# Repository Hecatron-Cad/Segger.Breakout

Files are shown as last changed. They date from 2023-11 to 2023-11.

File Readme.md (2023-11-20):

# Segger Breakout

This is a simple kicad design for a breakout board for the JLink Segger.

  * https://www.segger.com/products/debug-probes/j-link/models/j-link-edu/

It also has pads for connecting an ESP32 ProS3, or a Rpi Pico 2040
To clone use
```sh
git clone --recurse-submodules https://github.com/Hecatron-Cad/Segger.Breakout.git
```

## VCC Pins

I've added a jumper for the VCC input to VTref on the segger.
some pages suggest not to connect it when the device is powered over usb, but I think this is incorrect.
Still I added a jumper just in case anyway

  * https://www.visualmicro.com/page/ESP32-Debugging.aspx

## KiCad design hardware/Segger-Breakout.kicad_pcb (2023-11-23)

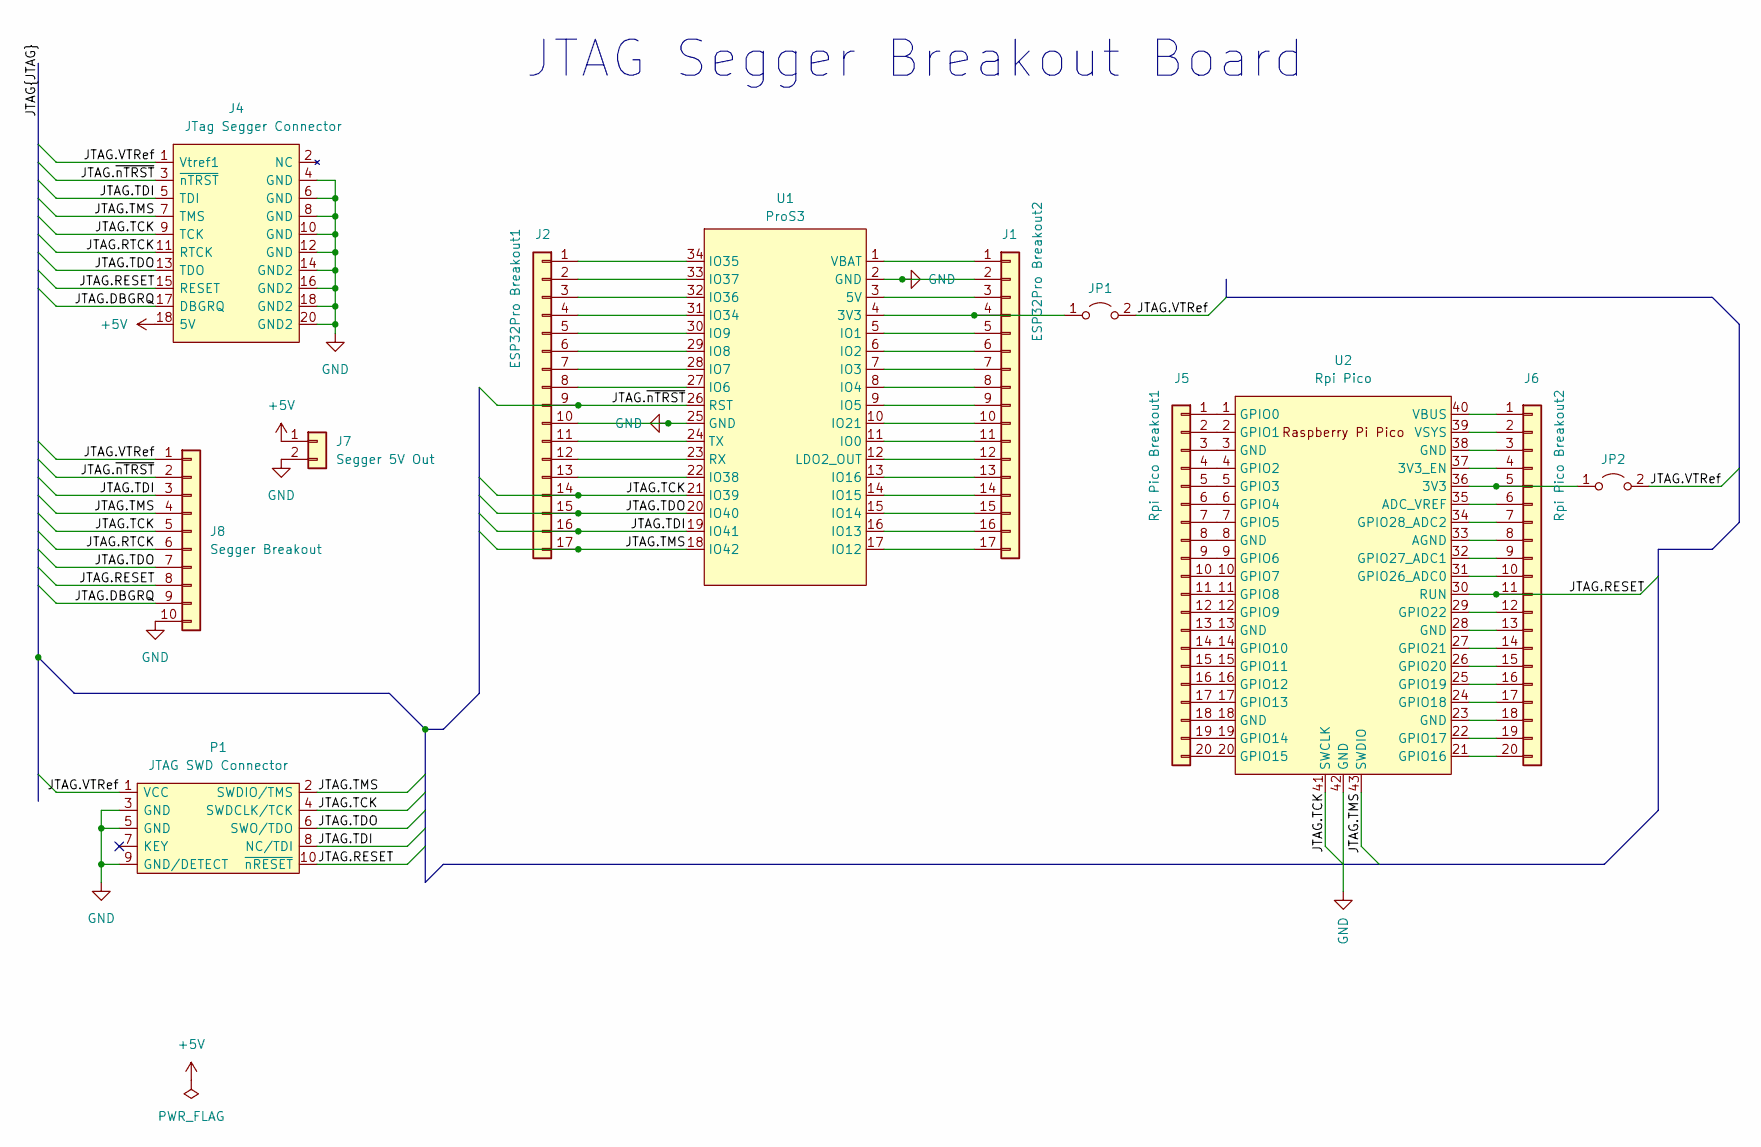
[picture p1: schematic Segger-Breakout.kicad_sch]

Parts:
J1: ESP32Pro Breakout2; PinHeader_1x17_P2.54mm_Vertical
J2: ESP32Pro Breakout1; PinHeader_1x17_P2.54mm_Vertical
J4: JTag Segger Connector; IDC-Header_2x10_P2.54mm_Vertical
J5: Rpi Pico Breakout1; PinHeader_1x20_P2.54mm_Vertical
J6: Rpi Pico Breakout2; PinHeader_1x20_P2.54mm_Vertical
J7: Segger 5V Out; PinHeader_1x02_P2.54mm_Vertical
J8: Segger Breakout; PinHeader_1x10_P2.54mm_Vertical
JP1, JP2: VTref Segger Input; PinSocket_1x02_P2.54mm_Vertical
P1: JTAG SWD Connector; ARM_10_PIN
U1: ProS3; ProS3_TH
U2: Rpi Pico; RPi_PicoW_SMD_TH

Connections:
/JTAG.DBGRQ: J4.17 (DBGRQ), J8.9
/JTAG.RESET: J4.15 (RESET), J6.11, J8.8, P1.10 (~nRESET), U2.30 (RUN)
/JTAG.RTCK: J4.11 (RTCK), J8.6
/JTAG.TCK: J2.14, J4.9 (TCK), J8.5, P1.4 (SWDCLK/TCK), U1.21 (IO39), U2.41 (SWCLK)
/JTAG.TDI: J2.16, J4.5 (TDI), J8.3, P1.8 (NC/TDI), U1.19 (IO41)
/JTAG.TDO: J2.15, J4.13 (TDO), J8.7, P1.6 (SWO/TDO), U1.20 (IO40)
/JTAG.TMS: J2.17, J4.7 (TMS), J8.4, P1.2 (SWDIO/TMS), U1.18 (IO42), U2.43 (SWDIO)
/JTAG.VTRef: J4.1 (Vtref1), J8.1, JP1.2 (B), JP2.2 (B), P1.1 (VCC)
/JTAG.~nTRST: J2.9, J4.3 (~nTRST), J8.2, U1.26 (RST)
unnamed: J1.1, U1.1 (VBAT)
unnamed: J1.3, U1.3 (5V)
unnamed: J1.4, JP1.1 (A), U1.4 (3V3)
unnamed: J1.5, U1.5 (IO1)
unnamed: J1.6, U1.6 (IO2)
unnamed: J1.7, U1.7 (IO3)
unnamed: J1.8, U1.8 (IO4)
unnamed: J1.9, U1.9 (IO5)
unnamed: J1.10, U1.10 (IO21)
unnamed: J1.11, U1.11 (IO0)
unnamed: J1.12, U1.12 (LDO2_OUT)
unnamed: J1.13, U1.13 (IO16)
unnamed: J1.14, U1.14 (IO15)
unnamed: J1.15, U1.15 (IO14)
unnamed: J1.16, U1.16 (IO13)
unnamed: J1.17, U1.17 (IO12)
unnamed: J2.1, U1.34 (IO35)
unnamed: J2.2, U1.33 (IO37)
unnamed: J2.3, U1.32 (IO36)
unnamed: J2.4, U1.31 (IO34)
unnamed: J2.5, U1.30 (IO9)
unnamed: J2.6, U1.29 (IO8)
unnamed: J2.7, U1.28 (IO7)
unnamed: J2.8, U1.27 (IO6)
unnamed: J2.11, U1.24 (TX)
unnamed: J2.12, U1.23 (RX)
unnamed: J2.13, U1.22 (IO38)
unnamed: J5.1, U2.1 (GPIO0)
unnamed: J5.2, U2.2 (GPIO1)
unnamed: J5.3, U2.3 (GND)
unnamed: J5.4, U2.4 (GPIO2)
unnamed: J5.5, U2.5 (GPIO3)
unnamed: J5.6, U2.6 (GPIO4)
unnamed: J5.7, U2.7 (GPIO5)
unnamed: J5.8, U2.8 (GND)
unnamed: J5.9, U2.9 (GPIO6)
unnamed: J5.10, U2.10 (GPIO7)
unnamed: J5.11, U2.11 (GPIO8)
unnamed: J5.12, U2.12 (GPIO9)
unnamed: J5.13, U2.13 (GND)
unnamed: J5.14, U2.14 (GPIO10)
unnamed: J5.15, U2.15 (GPIO11)
unnamed: J5.16, U2.16 (GPIO12)
unnamed: J5.17, U2.17 (GPIO13)
unnamed: J5.18, U2.18 (GND)
unnamed: J5.19, U2.19 (GPIO14)
unnamed: J5.20, U2.20 (GPIO15)
unnamed: J6.1, U2.40 (VBUS)
unnamed: J6.2, U2.39 (VSYS)
unnamed: J6.3, U2.38 (GND)
unnamed: J6.4, U2.37 (3V3_EN)
unnamed: J6.5, JP2.1 (A), U2.36 (3V3)
unnamed: J6.6, U2.35 (ADC_VREF)
unnamed: J6.7, U2.34 (GPIO28_ADC2)
unnamed: J6.8, U2.33 (AGND)
unnamed: J6.9, U2.32 (GPIO27_ADC1)
unnamed: J6.10, U2.31 (GPIO26_ADC0)
unnamed: J6.12, U2.29 (GPIO22)
unnamed: J6.13, U2.28 (GND)
unnamed: J6.14, U2.27 (GPIO21)
unnamed: J6.15, U2.26 (GPIO20)
unnamed: J6.16, U2.25 (GPIO19)
unnamed: J6.17, U2.24 (GPIO18)
unnamed: J6.18, U2.23 (GND)
unnamed: J6.19, U2.22 (GPIO17)
unnamed: J6.20, U2.21 (GPIO16)

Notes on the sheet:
JTAG Segger Breakout Board

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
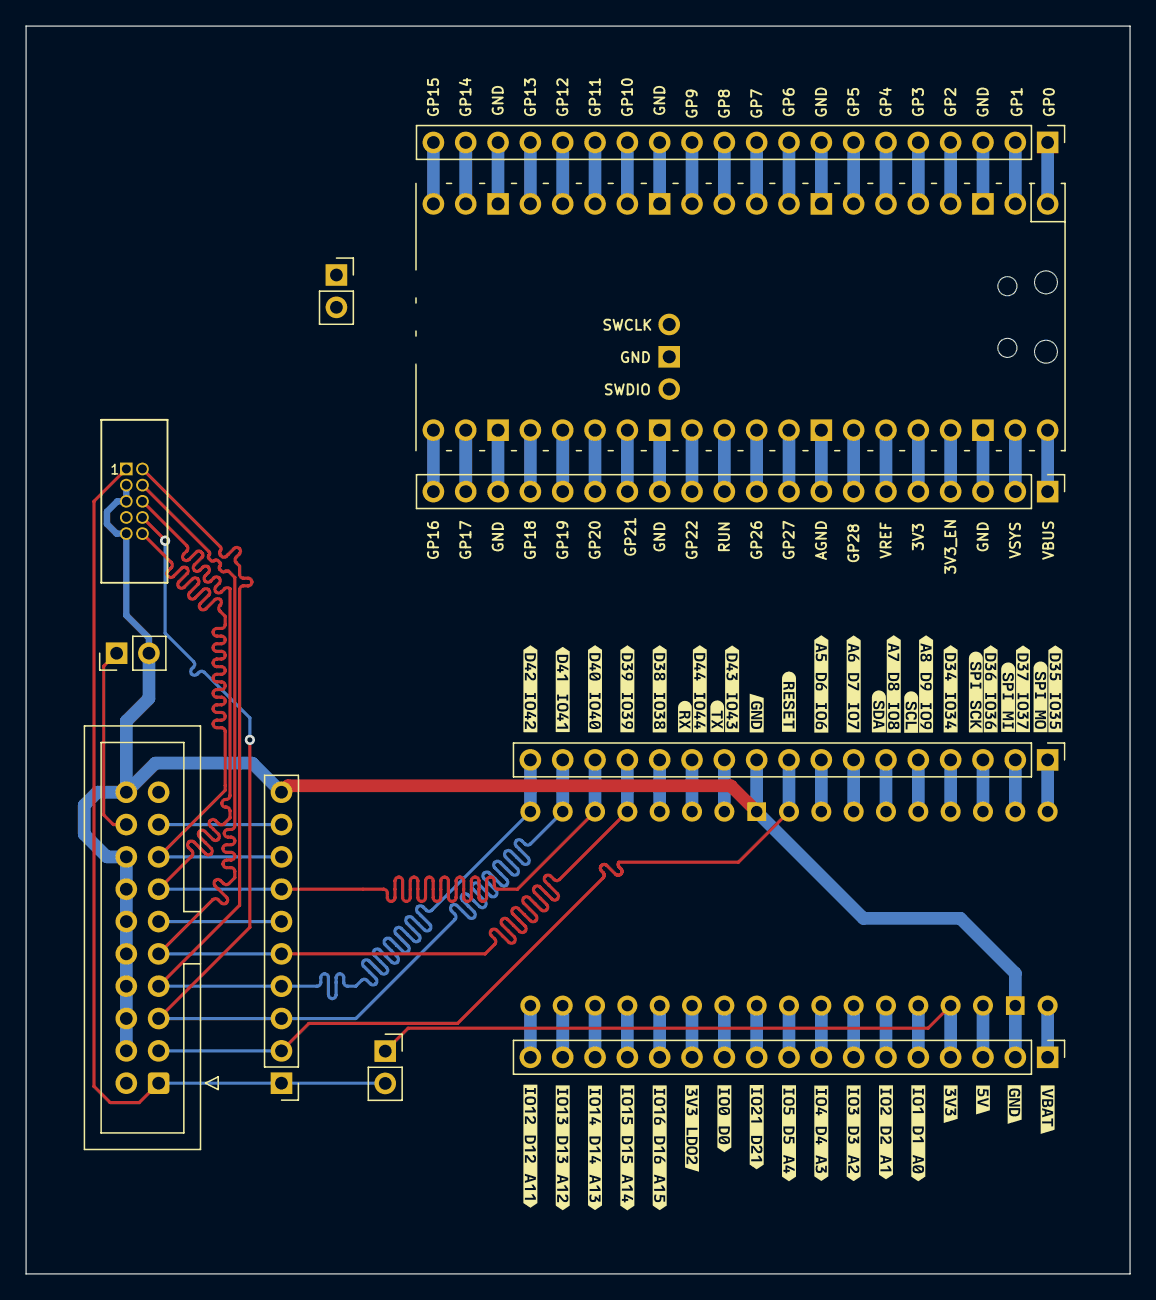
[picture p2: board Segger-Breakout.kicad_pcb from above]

Board: 2 copper layers, 86.7 x 98.0 mm, 53 parts (0 on the bottom side), 77 nets.

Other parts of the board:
kibuzzard-655FC4B1: G***; kibuzzard-655FC4B1
kibuzzard-655FC6B9: G***; kibuzzard-655FC6B9
kibuzzard-655FC7B2: G***; kibuzzard-655FC7B2
kibuzzard-655FC7D9: G***; kibuzzard-655FC7D9
kibuzzard-655FC9E7: G***; kibuzzard-655FC9E7
kibuzzard-655FC45E: G***; kibuzzard-655FC45E
kibuzzard-655FC52C: G***; kibuzzard-655FC52C
kibuzzard-655FC56D: G***; kibuzzard-655FC56D
kibuzzard-655FC60E: G***; kibuzzard-655FC60E
kibuzzard-655FC61C: G***; kibuzzard-655FC61C
kibuzzard-655FC469: G***; kibuzzard-655FC469
kibuzzard-655FC471: G***; kibuzzard-655FC471
kibuzzard-655FC478: G***; kibuzzard-655FC478
kibuzzard-655FC607: G***; kibuzzard-655FC607
kibuzzard-655FC616: G***; kibuzzard-655FC616
kibuzzard-655FC635: G***; kibuzzard-655FC635
kibuzzard-655FC710: G***; kibuzzard-655FC710
kibuzzard-655FC738: G***; kibuzzard-655FC738
kibuzzard-655FC940: G***; kibuzzard-655FC940
kibuzzard-655FC954: G***; kibuzzard-655FC954
kibuzzard-655FCA04: G***; kibuzzard-655FCA04
kibuzzard-655FCA7F: G***; kibuzzard-655FCA7F
kibuzzard-655FCA38: G***; kibuzzard-655FCA38
kibuzzard-655FCA61: G***; kibuzzard-655FCA61
kibuzzard-655FCAAA: G***; kibuzzard-655FCAAA
kibuzzard-655FCAFA: G***; kibuzzard-655FCAFA
kibuzzard-655FCB2A: G***; kibuzzard-655FCB2A
kibuzzard-655FCBAC: G***; kibuzzard-655FCBAC
kibuzzard-655FCC1E: G***; kibuzzard-655FCC1E
kibuzzard-655FCC6B: G***; kibuzzard-655FCC6B
kibuzzard-655FCC8E: G***; kibuzzard-655FCC8E
kibuzzard-655FCC41: G***; kibuzzard-655FCC41
kibuzzard-655FCCA3: G***; kibuzzard-655FCCA3
kibuzzard-655FCCAF: G***; kibuzzard-655FCCAF
kibuzzard-655FCD75: G***; kibuzzard-655FCD75
kibuzzard-655FCDA8: G***; kibuzzard-655FCDA8
kibuzzard-655FCDCF: G***; kibuzzard-655FCDCF
kibuzzard-655FCDDC: G***; kibuzzard-655FCDDC
kibuzzard-655FCE5C: G***; kibuzzard-655FCE5C
kibuzzard-655FCE13: G***; kibuzzard-655FCE13
kibuzzard-655FCE50: G***; kibuzzard-655FCE50

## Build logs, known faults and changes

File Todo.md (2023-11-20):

# TODO

  * PCB
  * For RP2040 Look at https://machinehum.medium.com/flashing-the-rp2040-with-a-jlink-and-openocd-b5c6806d51c2

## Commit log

2023-11-20 added submodule
    [Segger-Breakout.kicad_pcb, Segger-Breakout.kicad_sch]
2023-11-21 schematic updates
    [Segger-Breakout.kicad_sch]
2023-11-21 pcb updates
    [Segger-Breakout.kicad_pcb, Segger-Breakout.kicad_sch]
